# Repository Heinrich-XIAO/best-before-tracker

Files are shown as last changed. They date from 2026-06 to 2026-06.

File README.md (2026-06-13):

# foodsavr
~30% of food in the world is wasted and sent to landfills. foodsavr is a gadget that magnetically attaches to your fridge to remind you what food is close to expiring.

## Usage
To add a food item:
Show your food item to the camera and press the A button. Then, enter the expiry date of the item with the number pad. Finally, confirm by pressing the A button again. Press D to cancel.

Press B and C to cycle up and down through the list of food items.

## Technical Details
foodsavr uses two microcontrollers. The ESP-32 CAM is used for the camera, but since it doesn't have enough pins, another board is necessary. The other dev board is an off-brand pico-like RP2040 board. For the display, it uses an E-Ink display from WeAct Studio. The matrix keypad is your standard membrane keypad that is in every single electronics kit. It uses a set of lipos for power with USB-C charging. The charger board is TP4056-based.

## Build Guide
1. Insert the battery's JST connector into the charging board.
2. Insert the keypad's cable into its 1x8 header, with the keypad being in the slot on the top case.
3. Put the E-Ink display on the 2x4 header on the PCB.
4. Plop the top case on the display so that the screw holes of the display line up.
5. Use the M3 nuts and bolts to secure the display.
6. For the two corners on the right, insert the M3 heatset inserts into the holes.
7. Add a thin layer of cyanoacryalte glue around the bottom of the magnet holes. Then, insert the magnets.
8. Finally, fasten the bottom case so that the PCB rests in the tray with the M3.

## Motivation
I designed this because I got tired of leaving food at the back of my fridge to rot. Especially, since I'd save my favourite foods for later, and yet forget about them until expiry. This project reminds you before they expire so that you never leave food in the back of your fridge for too long.

## BOM
Go to BOM.csv for the Bill of Materials

## Exploded 3D Model


## Assembled 3D Model


https://cad.onshape.com/documents/8ee8f266d123a24e5a0ce496/w/151140d60200875ea61c9eed/e/18a74606bdcc9369348646ee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

## PCB
3D_PCB1_2026-06-06

## Schematic


## Zine Page


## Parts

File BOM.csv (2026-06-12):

Name | Links | Price (CAD)
PCB | https://jlcpcb.com/ | $6.66
E-Paper Screen | https://www.aliexpress.com/item/1005007133350270.html | $30.45
Ferrite Magnets (10x3mm) | https://www.aliexpress.com/item/1005008858265927.html | $11.24
Fake Pico | https://www.aliexpress.com/item/1005005617180169.html | $3.07
Number Pad | https://www.aliexpress.com/item/1005009455766218.html | $2.14
4x 18650 12000mAh | https://www.aliexpress.com/item/1005009903616172.html | $39.40
TP4056 JST USB-C Module | https://www.aliexpress.com/item/1005006943878636.html | $2.62
Voltage Booster | https://www.aliexpress.com/item/1005007385896399.html | $3.48
Right-Angle Headers | https://www.aliexpress.com/item/1005006795400618.html | $4.07
ESP32 CAM w/ Flasher | https://www.aliexpress.com/item/1005006137530316.html | $13.52
M3x10mm with nut | https://www.aliexpress.com/item/32799844538.html | $3.31
Heatset Inserts (M3 5mm OD w/ 10mm length) | https://www.aliexpress.com/item/1005003582355741.html | $3.93
Subtotal | N/A | $123.89
Total (After Aliexpress Discounts subject to change) | N/A | CAD$90.58
USD Total | N/A | USD$64.76

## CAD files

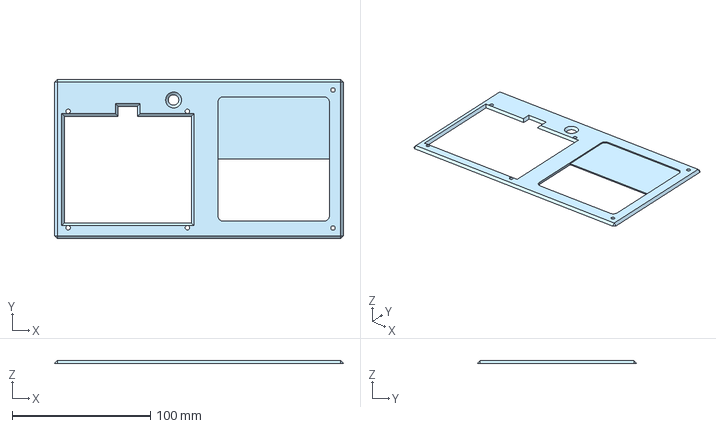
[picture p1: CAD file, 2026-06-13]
3d/top_case.step
209.0 x 115.0 x 2.00 mm

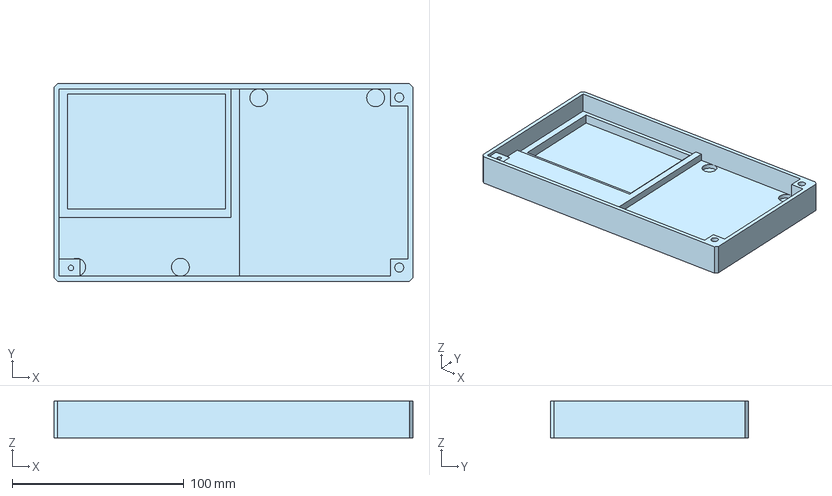
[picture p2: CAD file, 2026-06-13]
3d/bottom_case.step
209.0 x 115.0 x 21.3 mm

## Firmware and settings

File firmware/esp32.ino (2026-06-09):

#include "esp_camera.h"
#include "Arduino.h"
#include "FS.h"                // SD Card ESP32
#include "SD_MMC.h"            // SD Card ESP32
#include "soc/soc.h"           // Disable brownout problems
#include "soc/rtc_cntl_reg.h"  // Disable brownout problems
#include "driver/rtc_io.h"
#include <EEPROM.h>            // read and write from flash memory

// Define the number of bytes you want to access
#define EEPROM_SIZE 1

// Pin definition for CAMERA_MODEL_AI_THINKER
#define PWDN_GPIO_NUM     32
#define RESET_GPIO_NUM    -1
#define XCLK_GPIO_NUM      0
#define SIOD_GPIO_NUM     26
#define SIOC_GPIO_NUM     27

#define Y9_GPIO_NUM       35
#define Y8_GPIO_NUM       34
#define Y7_GPIO_NUM       39
#define Y6_GPIO_NUM       36
#define Y5_GPIO_NUM       21
#define Y4_GPIO_NUM       19
#define Y3_GPIO_NUM       18
#define Y2_GPIO_NUM        5
#define VSYNC_GPIO_NUM    25
#define HREF_GPIO_NUM     23
#define PCLK_GPIO_NUM     22

// Flash LED pin
#define FLASH_LED_PIN      4

int pictureNumber = 0;

void eeprom_init() {
  // Initialize EEPROM first to get picture number
  EEPROM.begin(EEPROM_SIZE);
  pictureNumber = EEPROM.read(0) + 1;
  
  // Handle overflow (reset to 1 if it exceeds 255)
  if (pictureNumber > 255) {
    pictureNumber = 1;
  }

  Serial.printf("Taking picture number: %d\n", pictureNumber);
}

void sd_card_init() {
  // Initialize SD Card BEFORE camera to reduce memory pressure
  Serial.println("Starting SD Card");
  if (!SD_MMC.begin()) {
    Serial.println("SD Card Mount Failed");
    goToSleep(); 
    return;
  }

  uint8_t cardType = SD_MMC.cardType();
  if (cardType == CARD_NONE) {
    Serial.println("No SD Card attached");
    goToSleep(); 
    return;
  }

  Serial.printf("SD Card Type: ");
  if (cardType == CARD_MMC) {
    Serial.println("MMC");
  } else if (cardType == CARD_SD) {
    Serial.println("SDSC");
  } else if (cardType == CARD_SDHC) {
    Serial.println("SDHC");
  } else {
    Serial.println("UNKNOWN");
  }
}

void camera_config() {
  // Camera configuration - REDUCED settings to prevent stack overflow
  camera_config_t config;
  config.ledc_channel = LEDC_CHANNEL_0;
  config.ledc_timer = LEDC_TIMER_0;
  config.pin_d0 = Y2_GPIO_NUM;
  config.pin_d1 = Y3_GPIO_NUM;
  config.pin_d2 = Y4_GPIO_NUM;
  config.pin_d3 = Y5_GPIO_NUM;
  config.pin_d4 = Y6_GPIO_NUM;
  config.pin_d5 = Y7_GPIO_NUM;
  config.pin_d6 = Y8_GPIO_NUM;
  config.pin_d7 = Y9_GPIO_NUM;
  config.pin_xclk = XCLK_GPIO_NUM;
  config.pin_pclk = PCLK_GPIO_NUM;
  config.pin_vsync = VSYNC_GPIO_NUM;
  config.pin_href = HREF_GPIO_NUM;
  config.pin_sccb_sda = SIOD_GPIO_NUM;
  config.pin_sccb_scl = SIOC_GPIO_NUM;
  config.pin_pwdn = PWDN_GPIO_NUM;
  config.pin_reset = RESET_GPIO_NUM;
  config.xclk_freq_hz = 20000000;
  config.pixel_format = PIXFORMAT_JPEG;

  // CRITICAL: Reduced frame size and quality to prevent stack overflow
  if (psramFound()) {
    Serial.println("PSRAM found");
    config.frame_size = FRAMESIZE_XGA;  // Reduced from UXGA to XGA
    config.jpeg_quality = 12;           // Increased from 10 to 12 (lower quality, smaller file)
    config.fb_count = 1;                // Reduced from 2 to 1 to save memory
  } else {
    Serial.println("PSRAM not found");
    config.frame_size = FRAMESIZE_VGA;  // Reduced from SVGA to VGA
    config.jpeg_quality = 15;           // Lower quality for boards without PSRAM
    config.fb_count = 1;
  }
  
  // Additional memory-saving configurations
  config.grab_mode = CAMERA_GRAB_LATEST; // Changed from WHEN_EMPTY to LATEST
}

void camera_init() {
  // Initialize Camera
  esp_err_t err = esp_camera_init(&config);
  if (err != ESP_OK) {
    Serial.printf("Camera init failed with error 0x%x\n", err);
    goToSleep();
    return;
  }
  Serial.println("Camera initialized successfully");

  // Additional sensor settings to optimize for memory usage
  sensor_t * s = esp_camera_sensor_get();
  if (s != NULL) {
    // Lower the resolution if needed
    // s->set_framesize(s, FRAMESIZE_VGA);
    
    // Optimize other settings
    s->set_brightness(s, 0);     // -2 to 2
    s->set_contrast(s, 0);       // -2 to 2
    s->set_saturation(s, 0);     // -2 to 2
    s->set_special_effect(s, 0); // 0 to 6 (0 - No Effect)
    s->set_whitebal(s, 1);       // 0 = disable , 1 = enable
    s->set_awb_gain(s, 1);       // 0 = disable , 1 = enable
    s->set_wb_mode(s, 0);        // 0 to 4 - if awb_gain enabled
    s->set_exposure_ctrl(s, 1);  // 0 = disable , 1 = enable
    s->set_aec2(s, 0);           // 0 = disable , 1 = enable
    s->set_ae_level(s, 0);       // -2 to 2
    s->set_aec_value(s, 300);    // 0 to 1200
    s->set_gain_ctrl(s, 1);      // 0 = disable , 1 = enable
    s->set_agc_gain(s, 0);       // 0 to 30
    s->set_gainceiling(s, (gainceiling_t)0);  // 0 to 6
    s->set_bpc(s, 0);            // 0 = disable , 1 = enable
    s->set_wpc(s, 1);            // 0 = disable , 1 = enable
    s->set_raw_gma(s, 1);        // 0 = disable , 1 = enable
    s->set_lenc(s, 1);           // 0 = disable , 1 = enable
    s->set_hmirror(s, 0);        // 0 = disable , 1 = enable
    s->set_vflip(s, 0);          // 0 = disable , 1 = enable
    s->set_dcw(s, 1);            // 0 = disable , 1 = enable
    s->set_colorbar(s, 0);       // 0 = disable , 1 = enable
  }
}

void shoot_and_save() {
  // Take Picture with Camera
  Serial.println("Taking picture...");
  camera_fb_t *fb = NULL;
  
  // Try to take picture with retries
  for (int retry = 0; retry < 3; retry++) {
    fb = esp_camera_fb_get();
    if (fb) break;
    Serial.printf("Camera capture failed, retry %d\n", retry + 1);
    delay(500);
  }
  
  if (!fb) {
    Serial.println("Camera capture failed after retries");
    goToSleep();
    return;
  }
  Serial.printf("Picture taken! Size: %zu bytes\n", fb->len);

  // Create file path
  String path = "/picture" + String(pictureNumber) + ".jpg";
  
  // Save picture to SD card
  fs::FS &fs = SD_MMC;
  Serial.printf("Picture file name: %s\n", path.c_str());

  File file = fs.open(path.c_str(), FILE_WRITE);
  if (!file) {
    Serial.println("Failed to open file in writing mode");
    esp_camera_fb_return(fb);
    goToSleep();
    return;
  }

  // Write file in chunks to prevent memory issues
  size_t totalBytes = fb->len;
  size_t bytesWritten = 0;
  const size_t chunkSize = 1024; // Write in 1KB chunks
  
  while (bytesWritten < totalBytes) {
    size_t toWrite = min(chunkSize, totalBytes - bytesWritten);
    size_t written = file.write(fb->buf + bytesWritten, toWrite);
    if (written != toWrite) {
      Serial.println("Write error occurred");
      break;
    }
    bytesWritten += written;
  }
  
  file.close();
  
  if (bytesWritten == totalBytes) {
    Serial.printf("Saved file to path: %s (%zu bytes)\n", path.c_str(), bytesWritten);
    
    // Update picture number in EEPROM only after successful save
    EEPROM.write(0, pictureNumber);
    EEPROM.commit();
    Serial.println("Picture saved successfully!");
  } else {
    Serial.printf("File write incomplete: %zu/%zu bytes\n", bytesWritten, totalBytes);
  }
  
  // Return the frame buffer immediately after use
  esp_camera_fb_return(fb);
}

void goToSleep() {
  // Deinitialize camera to free memory before sleep
  esp_camera_deinit();
  
  // Turn off the ESP32-CAM white on-board LED (flash) connected to GPIO 4
  pinMode(FLASH_LED_PIN, OUTPUT);
  digitalWrite(FLASH_LED_PIN, LOW);
  rtc_gpio_hold_en(GPIO_NUM_4);

  Serial.println("Going to sleep now");
  Serial.flush();
  
  delay(100);
  
  esp_sleep_enable_ext0_wakeup(16, 0);
  esp_deep_sleep_start();
}

void setup() {
  WRITE_PERI_REG(RTC_CNTL_BROWN_OUT_REG, 0);  // Disable brownout detector

  Serial.begin(115200);

  Serial1.begin(115200);
  Serial1.setTX(0);
  Serial1.setRX(16);

  goToSleep();
}

void loop() {
    if (Serial1.available()) {
        String cmd = Serial1.readStringUntil('\n');
        cmd.trim();

        if (cmd == "SHOOT") {
          Serial.println("Capturing photo...");
          eeprom_init();
          sd_card_init();

          camera_config();
          camera_init();

          // Wait a moment for camera to stabilize
          delay(1000);
          shoot_and_save();

          Serial.println("Photo Captured...");
          // Brief delay before sleep
          delay(500);
          goToSleep();
        }
    } else {
        Serial.println("Serial1 not available.")
    }
}

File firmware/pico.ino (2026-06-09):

const uint8_t ROWS = 4;
const uint8_t COLS = 4;

const uint8_t rowPins[ROWS] = {7, 6, 5, 4};
const uint8_t colPins[COLS] = {3, 2, 1, 0};

const char keymap[ROWS][COLS] = {
  {'1', '2', '3', 'A'},
  {'4', '5', '6', 'B'},
  {'7', '8', '9', 'C'},
  {'*', '0', '#', 'D'}
};

void setup() {
  Serial1.setTX(12);  // GP12
  Serial1.setRX(13);  // GP13
  Serial1.begin(115200);
  Serial.begin(115200);

  // Rows are outputs
  for (int r = 0; r < ROWS; r++) {
    pinMode(rowPins[r], OUTPUT);
    digitalWrite(rowPins[r], HIGH);
  }

  // Columns are inputs with pullups
  for (int c = 0; c < COLS; c++) {
    pinMode(colPins[c], INPUT_PULLUP);
  }

  Serial.println("Ready");
}

char scanKeypad() {
  for (int r = 0; r < ROWS; r++) {
    // Activate this row
    digitalWrite(rowPins[r], LOW);

    delayMicroseconds(5);

    for (int c = 0; c < COLS; c++) {
      if (digitalRead(colPins[c]) == LOW) {
        digitalWrite(rowPins[r], HIGH);
        return keymap[r][c];
      }
    }

    digitalWrite(rowPins[r], HIGH);
  }

  return '\0';
}

int date[8] = {2, 0, -1, -1, -1, -1, -1, -1};

#define START_MENU 0
#define CAMERA 1
#define ENTER_DATE 2

int state = START_MENU;

void enterDate(char key) {
  int digit = key - '0';
  int i = 0;
  while (date[i] != -1) {
    i++;
  }
  date[i] = digit;

  for (int i = 0; i < 8; i++) {
    if (date[i] != -1) {
      Serial.print(date[i]);
      if (i == 3 || i == 5) {
        Serial.print('-');
      }
    }
  }
  Serial.println("");
}

void loop() {
  static char lastKey = '\0';

  char key = scanKeypad();

  if (key != '\0' && key != lastKey) {
    if (key >= '0' && key <= '9' && state == ENTER_DATE) {
      enterDate(key);
    }

    if (key == 'D' && state == ENTER_DATE && date[2] != -1) {
      int i = 7;
      while (date[i] == -1) {
        i--;
      }
      date[i] = -1; 


      for (int i = 0; i < 8; i++) {
        if (date[i] != -1) {
          Serial.print(date[i]);
          if (i == 3 || i == 5) {
            Serial.print('-');
          }
        }
      }
      Serial.println("");
    }

    if (key == 'A' && state == START_MENU) {
      state = CAMERA;
      Serial1.write(0x01);
    }
    if (key == 'A' && state == CAMERA) {
      state = ENTER_DATE;
      Serial1.print("SHOOT");
    }
    
    if (key == 'A' && state == ENTER_DATE) {
      state = START_MENU;
      int resetVals[8] = {2, 0, -1, -1, -1, -1, -1, -1};

      for (int i = 0; i < 8; i++) {
          date[i] = resetVals[i];
      }
    }
  }

  lastKey = key;

  delay(50);
}

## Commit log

2026-05-31 Add BOM section with component links to README
    Added a Bill of Materials (BOM) section with links to components.
2026-06-02 Add Number Pad 4x4 to BOM list
2026-06-03 Add 3.7v to 5v Booster link to README
2026-06-05 Update RP2040 Pico description in README
2026-06-06 Fix capitalization in product link
    Corrected the capitalization of '3.7v to 5v Booster' to '3.7V to 5V Booster'.
2026-06-06 Add schematic section with image to README
    Added schematic image section to README.
2026-06-06 Add motivation section to README
    Added a motivation section explaining the purpose of the device.
2026-06-06 rename file
    [BOM.csv]
2026-06-06 add esp32 and total/subtotal
    [BOM.csv]
2026-06-06 add usd conversion
    [BOM.csv]
2026-06-06 pcb files
2026-06-06 update bom with deez nuts
    [BOM.csv]
2026-06-07 remove last unnecessary line break at the end of bom file
    [BOM.csv]
2026-06-07 remove spaces from .csv to fix fallout submission problem
    [BOM.csv]
2026-06-08 update pico ino firmware to remove useless switch and to setup serial
2026-06-08 esp32 ino firmware
2026-06-12 round corners of PCB
2026-06-12 clarify description for ferrite magnets
    [BOM.csv]
2026-06-12 change length of screw
    [BOM.csv]
2026-06-13 3d models
    [bottom_case.step, top_case.step]
2026-06-13 add ferrite magnet related instructions to the build guide.
